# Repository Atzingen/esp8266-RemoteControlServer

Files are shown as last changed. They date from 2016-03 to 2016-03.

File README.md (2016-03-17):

# esp8266-RemoteControlServer

#### Software and Electronics (PCB and schematic) for a esp8266-12e board remote control

This is a project (both software and hardware) for an web controlled IR (infra Read) emitter using an esp8266 microcontroller.

The software in esp8266 is a webserver that serves an single-page web interface (figure 2) with the control buttons for the desired IF device (TV, AC, or other), using html and bootstrap css. The esp8266 webserver also receives GET requests from each specific button. Button pressed requests are done asynchronous using ajax with the help of Jquery mobile library.

The electronic board pcb is composed of the eso8266 model 12-e with the bare minimal components for use, a Infra Read LED emitter and a linear power regulator to enable the use of 5V power supplies. The schematics are available in eagle files in the "pcb" folder and printable pdf files fot pcb etching.

Photos
=========

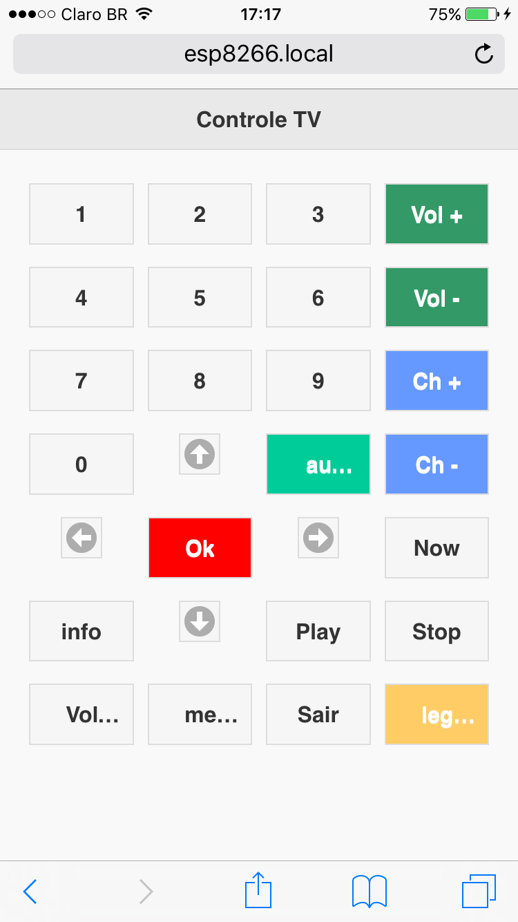
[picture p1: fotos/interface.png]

Figure 1 - Interface provided by the esp8266 webserver.

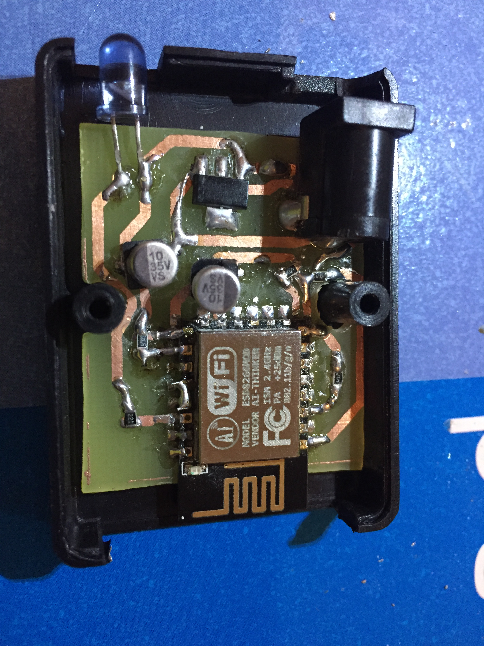
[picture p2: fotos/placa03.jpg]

Figure 2 - Assembled board. 4.5 to 9V input.

Authors
=========

Gustavo Voltani von Atzingen

References
=========

1- https://github.com/esp8266/Arduino

2- http://bbs.espressif.com/

3- http://www.esp8266.com/

4- https://github.com/markszabo/IRremoteESP8266

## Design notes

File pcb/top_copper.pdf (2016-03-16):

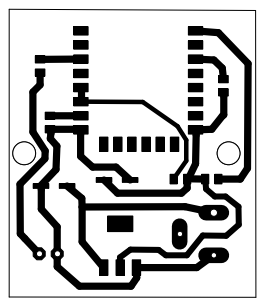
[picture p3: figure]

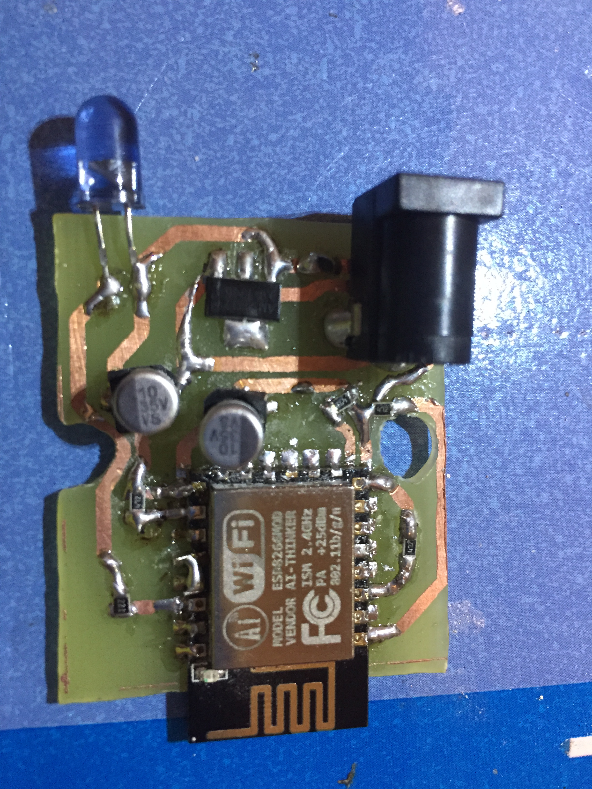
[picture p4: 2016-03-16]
fotos/placa01.jpg

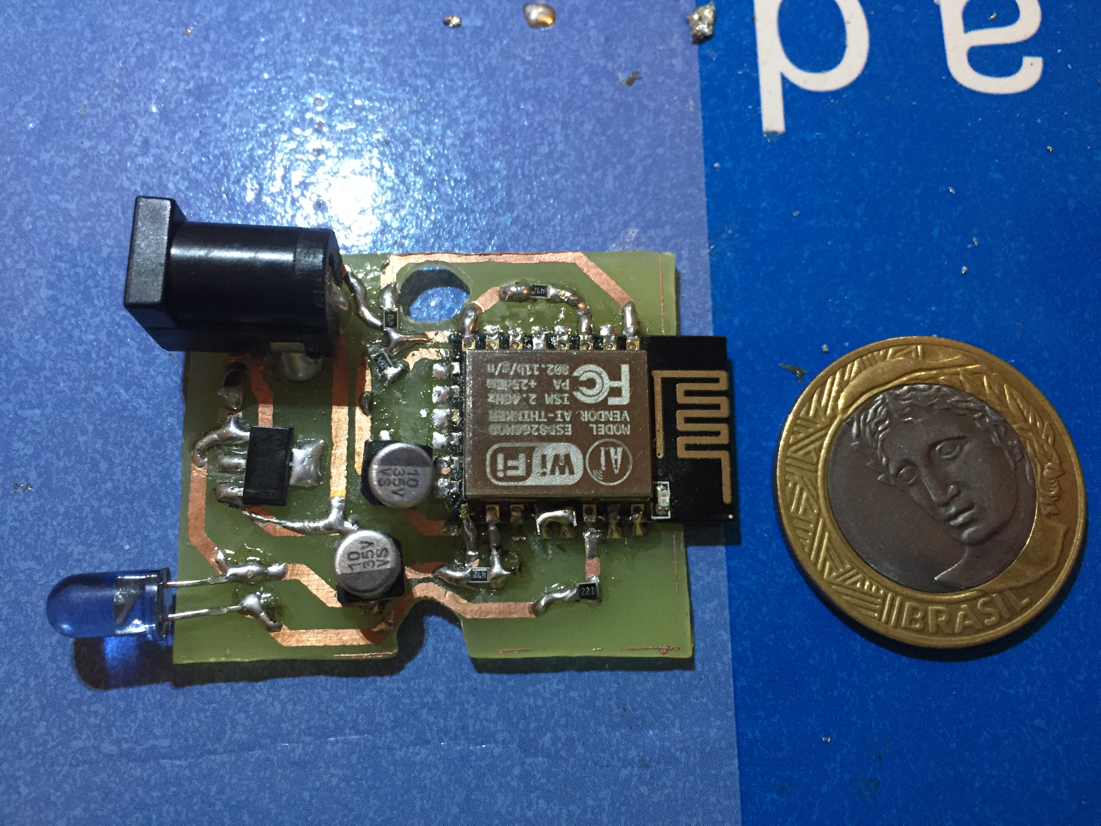
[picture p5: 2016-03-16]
fotos/placa02.jpg

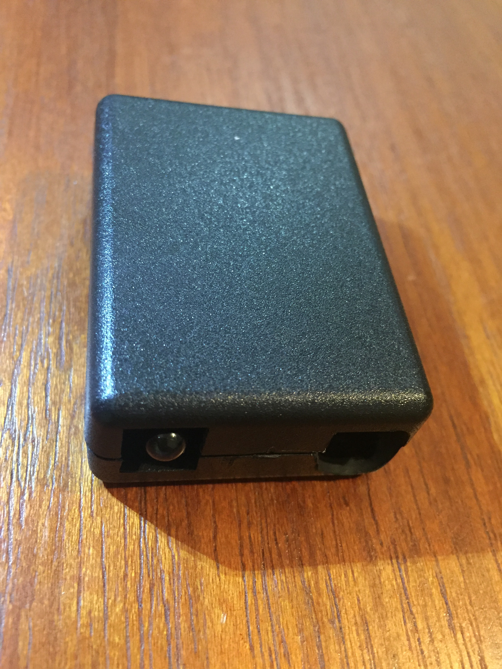
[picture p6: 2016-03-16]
fotos/caixa.jpg

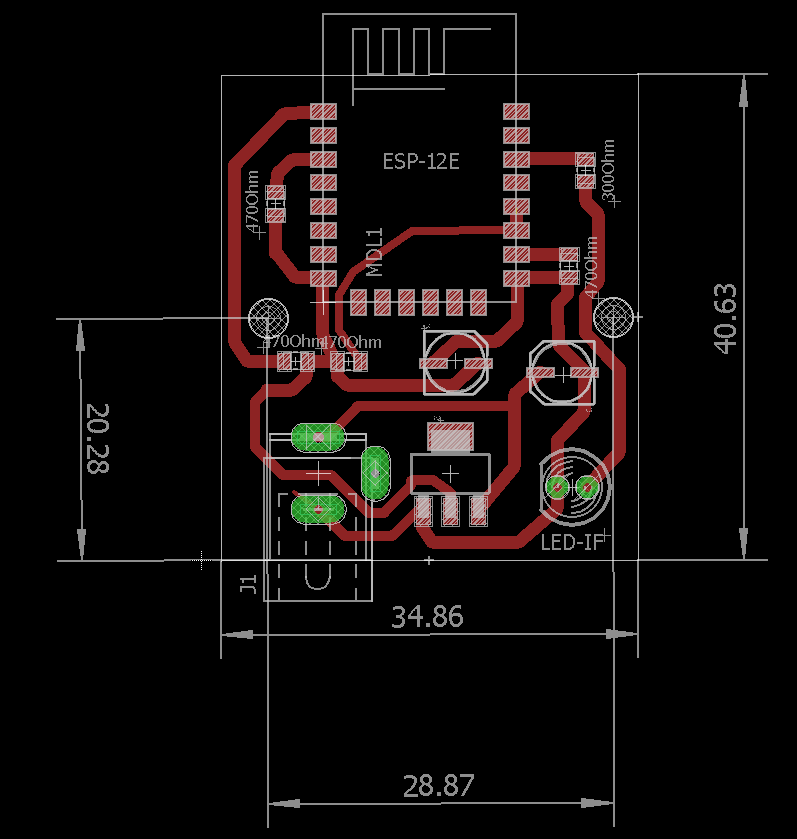
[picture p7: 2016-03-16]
fotos/pcb-esquema.PNG

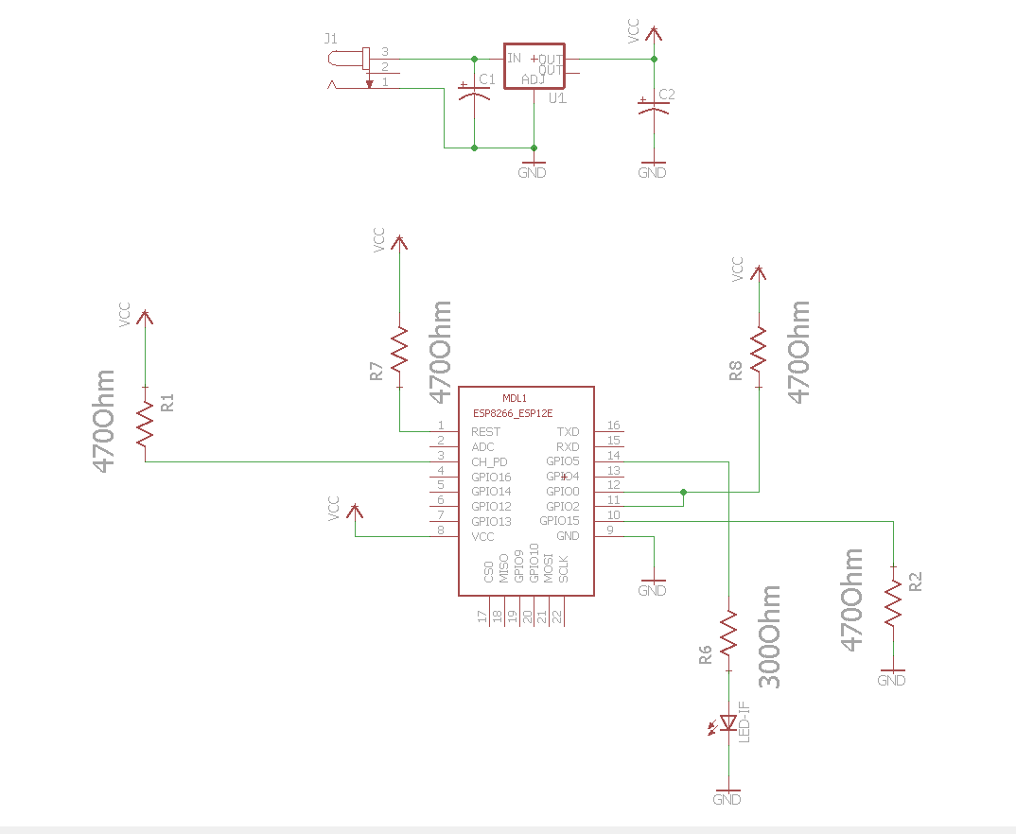
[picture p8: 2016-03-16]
fotos/esquematico.PNG

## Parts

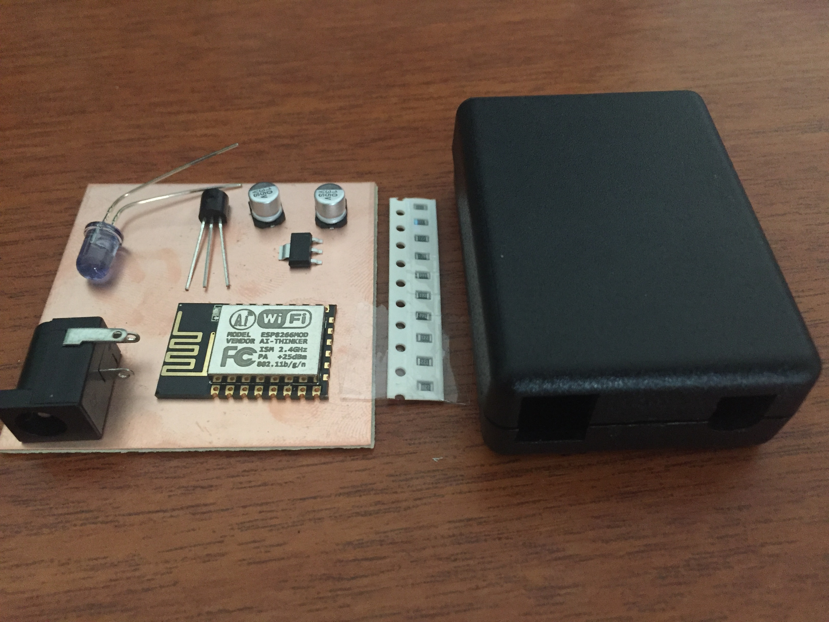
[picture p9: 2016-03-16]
fotos/componentes.jpg

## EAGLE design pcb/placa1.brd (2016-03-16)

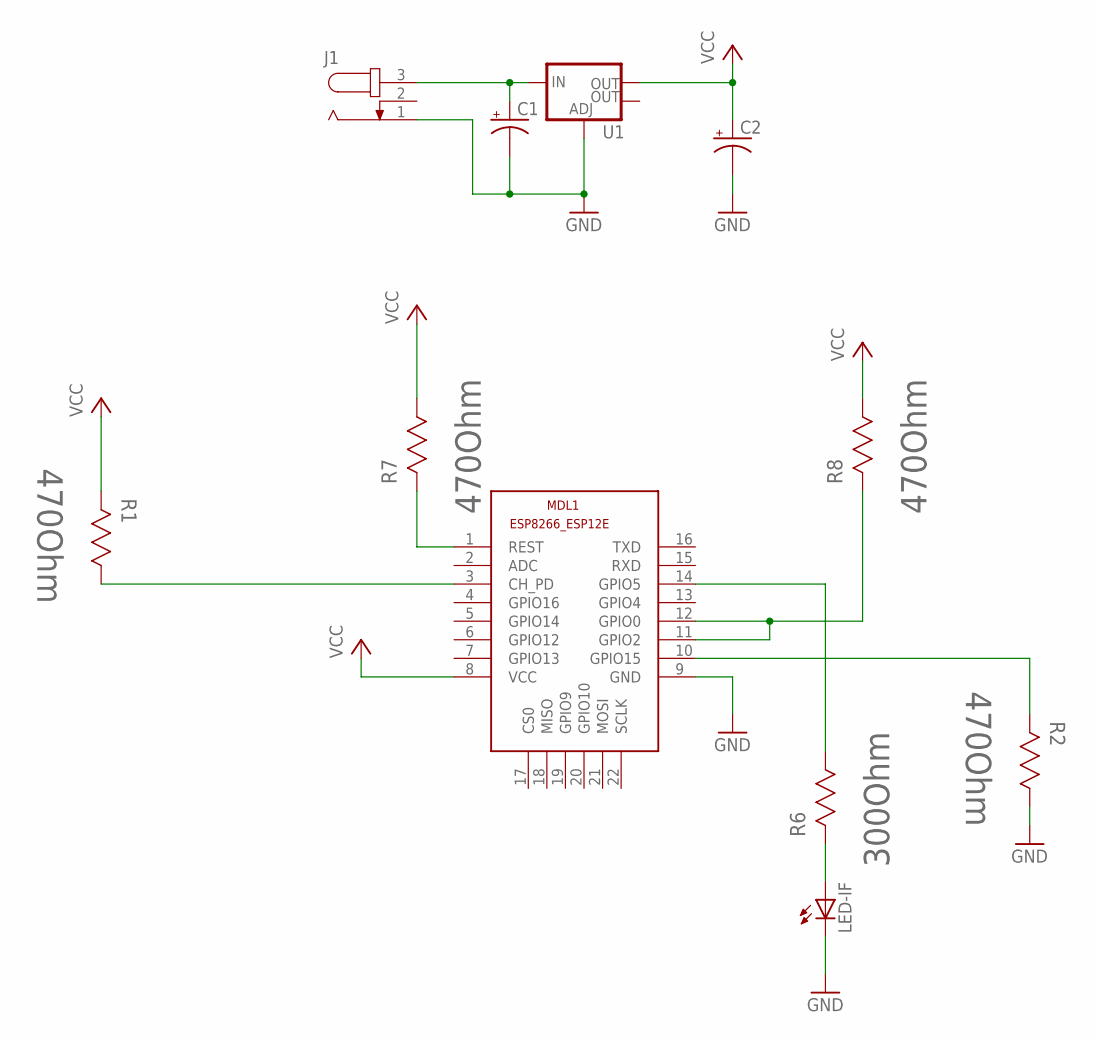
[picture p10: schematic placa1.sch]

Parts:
C1, C2: CAP_POLC; PANASONIC_C
J1: JACK-PLUG0; SPC4077
LED-IF: LED5MM
MDL1: ESP8266-12EESP8266-ESP12E; ESP8266-ESP12E
R1, R2, R7, R8: 470Ohm; RESC2013X65N
R6: 300Ohm; RESC2013X65N
U1: V_REG_LM1117SOT223; SOT223

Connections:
GND: C1.-, C2.-, J1.1, LED-IF.K (C), MDL1.9 (GND), R2.1 (R1), U1.1 (ADJ)
unnamed: MDL1.3 (CH_PD), R1.1 (R1)
unnamed: MDL1.10 (GPIO15), R2.2 (R2)
unnamed: MDL1.11 (GPIO2), MDL1.12 (GPIO0), R8.2 (R2)
unnamed: MDL1.1 (REST), R7.2 (R2)
unnamed: MDL1.14 (GPIO5), R6.1 (R1)
unnamed: C1.+, J1.3, U1.3 (IN)
unnamed: LED-IF.A, R6.2 (R2)
VCC: C2.+, MDL1.8 (VCC), R1.2 (R2), R7.1 (R1), R8.1 (R1), U1.2 (OUT)

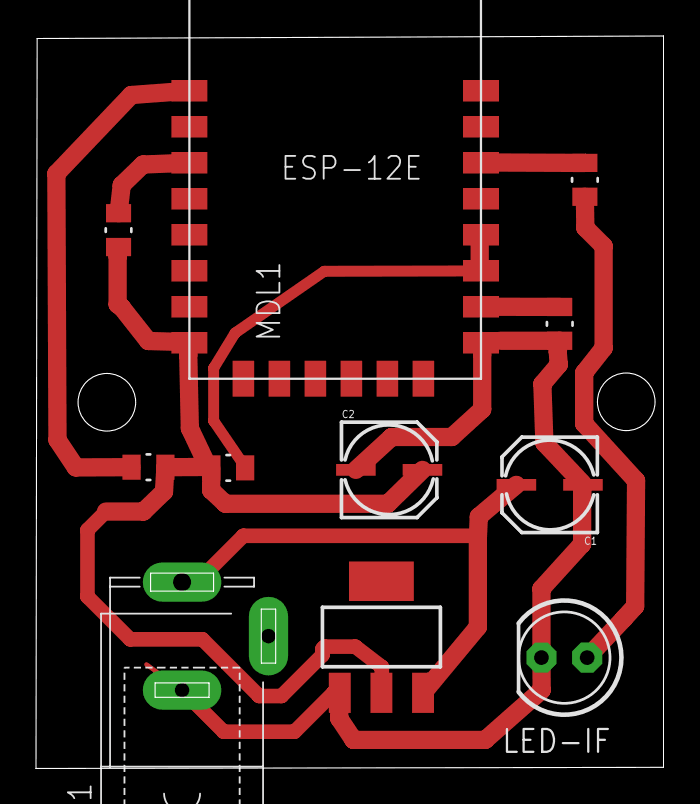
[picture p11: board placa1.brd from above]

Board: 2 copper layers, 34.9 x 40.7 mm, 11 parts (0 on the bottom side), 9 nets.

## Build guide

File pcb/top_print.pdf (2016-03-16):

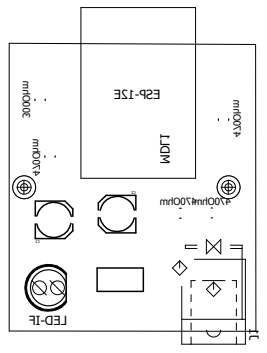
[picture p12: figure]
470Ohm 470Ohm 300Ohm; 470Ohm470Ohm C1 C2 J1; LED-IF MDL1 ESP-12E

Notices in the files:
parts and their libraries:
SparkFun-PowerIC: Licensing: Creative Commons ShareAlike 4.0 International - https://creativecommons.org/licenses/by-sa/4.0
